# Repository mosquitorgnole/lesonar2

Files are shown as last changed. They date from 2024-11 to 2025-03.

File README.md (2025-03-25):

LeSonar 2
=========

We're directly selling our ultrasonic sonar development kit, and releasing it under an AGPL license so you can build projects on top of our sensor.

Links
-----
- [Main project link](https://tornyol.com/sonar)

Photos
------

 

Specifications
--------------

*   380x TDK Invensense T3902 PDM microphones.
*   Artix-7 A100T FPGA.
*   FT601Q parralel-to-usb bridge tested at up to 200MB/s.
*   32x 40khz Ultrasonic Piezoelectric emitters
*   2 free GPIOs

Capabilities
------------

### Active sonar

*   Optimized for 40KHz operation.
*   Up to 5°x5° beamwidth.
*   Range up to 8 meters depending on target sonar cross-section.

### Passive sonar

*   Can detect a bike air chamber leak at 3 meters.

Software
========

The sonar comes with two demoes
\- 2D Slicing camera, that shows the energyscape for a specific distance.
\- 3D Camera, that shows the reflected energy with a 3d point cloud.

Both examples are made with C99 C, using Raylib and Sokol for real-time 2D/3D visualization.

Attribution
======
The receiver hardware is based on the open-source [CP SoM One](https://github.com/controlpaths/cp_som_one)

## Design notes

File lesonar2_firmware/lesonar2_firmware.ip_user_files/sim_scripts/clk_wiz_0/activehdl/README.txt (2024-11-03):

################################################################################
# Vivado (TM) v2023.1 (64-bit)
#
# README.txt: Please read the sections below to understand the steps required to
#             run the exported script and how to fetch design source file details
#             from the file_info.txt file.
#
# Generated by export_simulation on Thu Mar 14 17:59:51 +0100 2024
#
################################################################################

1. Steps to run the generated simulation script

From the shell prompt in the current directory, issue the following command:-

./clk_wiz_0.sh

This command will launch the 'compile', 'elaborate' and 'simulate' functions
implemented in the script file for the 3-step flow. These functions are called
from the main 'run' function in the script file.

The 'run' function first calls the 'check_args' function, the purpose of which
is to verify the generated script arguments and print error if incorrect switch
is specified. The 'run' function then calls the 'setup' function, the purpose of
which is to specify custom or initialization commands. The function also executes
following sub-functions:-
'reset_run' if -reset_run switch is specified.
'reset_log' if -reset_log switch is specified.

The purpose of 'reset_run' function' is to delete the simulator generated design
data from the previous run and the purpose of 'reset_log' function' is to delete
the simulator generated log files.

The 'run' function then calls the 'init_lib' function, the purpose of which is to
create design library mappings and directories. This function is called before the
'compile' step. By default, if '-step' switch is specified with the script then the
script will execute that specfic step, else it will execute all steps applicable
for the target simulator.

For more information on the script, please type './clk_wiz_0.sh -help'

2. Design source file information

export_simulation generates a 'file_info.txt' file that contains design file information
based on the compile order when export_simulation was executed from Vivado. The file
contains information about the file name, type, library it is compiled into, whether
it is part of the IP, associated library, file path information in a comma separated
format. This file can be parsed to extract the required information for generating a
custom script or can be read from verification test infra.

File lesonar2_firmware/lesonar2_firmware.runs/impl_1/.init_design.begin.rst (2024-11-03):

<?xml version="1.0"?>
<ProcessHandle Version="1" Minor="0">
    <Process Command=".planAhead." Owner="alex" Host="" Pid="918656">
    </Process>
</ProcessHandle>

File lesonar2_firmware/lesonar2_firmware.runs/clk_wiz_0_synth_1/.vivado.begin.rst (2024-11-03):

<?xml version="1.0"?>
<ProcessHandle Version="1" Minor="0">
    <Process Command="vivado.bat" Owner="toussaint" Host="DESKTOP-L8QVRO0" Pid="20144" HostCore="16" HostMemory="017126408192">
    </Process>
</ProcessHandle>

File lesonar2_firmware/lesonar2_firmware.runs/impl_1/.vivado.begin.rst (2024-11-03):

<?xml version="1.0"?>
<ProcessHandle Version="1" Minor="0">
    <Process Command="vivado" Owner="alex" Host="atlap" Pid="918612" HostCore="8" HostMemory="16124260">
    </Process>
</ProcessHandle>

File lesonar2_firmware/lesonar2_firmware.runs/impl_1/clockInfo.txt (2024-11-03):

-------------------------------------
| Tool Version : Vivado v.2023.2
| Date         : Mon Oct 28 13:15:07 2024
| Host         : atlap
| Design       : design_1
| Device       : xc7a100t-fgg484-2--
-------------------------------------

For more information on clockInfo.txt clock routing debug file see https://support.xilinx.com/s/article/000035660?language=en_US

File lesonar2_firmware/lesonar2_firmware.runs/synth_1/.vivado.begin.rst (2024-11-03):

<?xml version="1.0"?>
<ProcessHandle Version="1" Minor="0">
    <Process Command="vivado" Owner="alex" Host="atlap" Pid="915598" HostCore="8" HostMemory="16124260">
    </Process>
</ProcessHandle>

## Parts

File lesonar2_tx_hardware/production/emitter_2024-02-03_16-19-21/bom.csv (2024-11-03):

Designator | Footprint | Quantity | Value | LCSC Part #
C1, C2 | CP_Elec_6.3x5.4 | 2 | 33uF | C72508
D1 | D_SMA | 1 | SS34 | C8678
H2, H4, H5, H6 | MountingHole_2.2mm_M2_DIN965_Pad_TopBottom | 4 | MountingHole_Pad | DNP
J1 | PinHeader_1x05_P2.54mm_Vertical | 1 | Conn_01x05_Pin
L1 | L_Sunlord_MWSA0503S | 1 | 22uH | C718383
LS1, LS10, LS11, LS12, LS13, LS14, LS15, LS16, LS17, LS18, LS19, LS2, LS20, LS21, LS22, LS23, LS24, LS25, LS26, LS27, LS28, LS29, LS3, LS30, LS31, LS32, LS4, LS5, LS6, LS7, LS73, LS74, LS75_2, LS75, LS76_2, LS76, LS77, LS78, LS79_2, LS79, LS8, LS80_2, LS80, LS81, LS82, LS83_2, LS83, LS84_2, LS84, LS85, LS86, LS87_2, LS87, LS88_2, LS88, LS9 | XDCR_MA40S4S | 56 | MA40S4S
R1 | 0603 | 1 | 82k
R2 | 0603 | 1 | 2k2
R3 | 0603 | 1 | 0.2
U1 | SOT-23-6 | 1 | MT3608 | C84817
U2 | Texas_HTSOP-8-1EP_3.9x4.9mm_P1.27mm_EP2.95x4.9mm_Mask2.4x3.1mm_ThermalVias | 1 | DRV8870DDA

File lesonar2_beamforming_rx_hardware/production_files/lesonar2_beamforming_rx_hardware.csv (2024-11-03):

# | Reference | Qty | Value | Footprint | DNP | JLCPCB
1 | C1, C3, C5, C7, C8, C9, C10, C11, C12, C13, C25, C26, C27, C28, C35, C36, C37, C38, C39 | 19 | 4u7 | Capacitor_SMD:C_0805_2012Metric |  | C162420
2 | C2, C4, C6 | 3 | 10u | Capacitor_SMD:C_0805_2012Metric |  | C105505
3 | C14, C15, C16, C17, C18, C19, C20, C21, C22, C29, C30, C31, C32, C40, C41, C42, C43, C44, C45, C46 | 20 | 0.47u | Capacitor_SMD:C_0402_1005Metric |  | C106255
4 | C23, C24 | 2 | 47u | Capacitor_SMD:C_1206_3216Metric |  | C385907
5 | C33, C34 | 2 | 100u | Capacitor_SMD:C_1206_3216Metric |  | C268006
6 | D1 | 1 | DONE | LED_SMD:LED_0603_1608Metric |  | C89814
7 | D2 | 1 | VCC | LED_SMD:LED_0603_1608Metric |  | C601673
8 | D3, D4, D5 | 3 | USER_LED | LED_SMD:LED_0603_1608Metric |  | C40378
9 | L1, L2, L3 | 3 | 2u2 | inductors:IND_LQH3NPN2R2MJRL |  | C341775
10 | R1 | 1 | 100k | Resistor_SMD:R_0402_1005Metric |  | C131362
11 | R2, R5 | 2 | 22k | Resistor_SMD:R_0402_1005Metric |  | C409681
12 | R3 | 1 | 120k | Resistor_SMD:R_0402_1005Metric |  | C323683
13 | R4 | 1 | 240k | Resistor_SMD:R_0402_1005Metric |  | C323663
14 | R6 | 1 | 33k | Resistor_SMD:R_0402_1005Metric |  | C416388
15 | R7, R8, R9, R10, R15, R16, R17 | 7 | 4k7 | Resistor_SMD:R_0402_1005Metric |  | C3017492
16 | R11 | 1 | 330 | Resistor_SMD:R_0402_1005Metric |  | C881192
17 | R12, R13, R14, R19 | 4 | 10k | Resistor_SMD:R_0402_1005Metric |  | C328298
18 | R18 | 1 | 100 | Resistor_SMD:R_0402_1005Metric |  | C471762
19 | U1 | 1 | XC7A75T-FGG484 | Package_BGA:FB-BGA-484_23.0x23.0mm_Layout22x22_P1.0mm |  | C396343
20 | U2 | 1 | TLV62565DBVR | Package_TO_SOT_SMD:SOT-23-5 |  | C87122
21 | U3, U4 | 2 | TLV62565DBVR | Package_TO_SOT_SMD:SOT-23-5 |  | C23902
22 | U5 | 1 | MX25L12833F | Package_SON:WSON-8-1EP_6x5mm_P1.27mm_EP3.4x4mm |  | C2802709
23 | X1 | 1 | SG-8018CE | Crystal:Crystal_SMD_3225-4Pin_3.2x2.5mm |  | C390488

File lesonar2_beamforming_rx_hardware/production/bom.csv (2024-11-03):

Designator | Footprint | Quantity | Value | LCSC Part #
C1, C10, C11, C12, C13, C25, C26, C27, C28, C3, C35, C36, C37, C38, C39, C44, C45, C468, C5, C51, C67, C68, C69, C7, C70, C71, C72, C73, C8, C9 | 0805 | 30 | 4u7 | C162420
C100, C101, C102, C103, C104, C105, C106, C107, C108, C109, C110, C111, C112, C113, C114, C115, C116, C117, C118, C119, C120, C121, C122, C123, C124, C125, C126, C127, C128, C129, C130, C131, C132, C133, C134, C135, C136, C137, C138, C139, C140, C141, C142, C143, C144, C145, C146, C147, C148, C149, C150, C151, C152, C153, C154, C155, C156, C157, C158, C159, C160, C161, C162, C163, C164, C165, C166, C167, C168, C169, C170, C171, C172, C173, C174, C175, C176, C177, C178, C179, C180, C181, C182, C183, C184, C185, C186, C187, C188, C189, C190, C191, C192, C193, C194, C195, C196, C197, C198, C199, C200, C201, C202, C203, C204, C205, C206, C207, C208, C209, C210, C211, C212, C213, C214, C215, C216, C217, C218, C219, C220, C221, C222, C223, C224, C225, C226, C227, C228, C229, C230, C231, C232, C233, C234, C235, C236, C237, C238, C239, C240, C241, C242, C243, C244, C245, C246, C247, C248, C249, C250, C251, C252, C253, C254, C255, C256, C257, C258, C259, C260, C261, C262, C263, C264, C265, C266, C267, C268, C269, C270, C271, C272, C273, C274, C275, C276, C277, C278, C279, C280, C281, C282, C283, C284, C285, C286, C287, C288, C289, C290, C291, C292, C293, C294, C295, C296, C297, C298, C299 | 0201 | 200 | 0.1u
C14, C15, C16, C17, C18, C19, C20, C21, C22, C29, C30, C31, C32, C40, C41, C42, C43, C466, C467, C55, C56, C57, C58, C59, C61, C62, C63, C64, C65 | 0402 | 29 | 0.47u | C106255
C2, C4, C6 | 0805 | 3 | 10u | C105505
C23, C24, C470, C60, C66 | 1206 | 5 | 47u | C385907
C300, C301, C302, C303, C304, C305, C306, C307, C308, C309, C310, C311, C312, C313, C314, C315, C316, C317, C318, C319, C320, C321, C322, C323, C324, C325, C326, C327, C328, C329, C330, C331, C332, C333, C334, C335, C336, C337, C338, C339, C340, C341, C342, C343, C344, C345, C346, C347, C348, C349, C350, C351, C352, C353, C354, C355, C356, C357, C358, C359, C360, C361, C362, C363, C364, C365, C366, C367, C368, C369, C370, C371, C372, C373, C374, C375, C376, C377, C378, C379, C380, C381, C382, C383, C384, C385, C386, C387, C388, C389, C390, C391, C392, C393, C394, C395, C396, C397, C398, C399, C400, C401, C402, C403, C404, C405, C406, C407, C408, C409, C410, C411, C412, C413, C414, C415, C416, C417, C418, C419, C420, C421, C422, C423, C424, C425, C426, C427, C428, C429, C430, C431, C432, C433, C434, C435, C436, C437, C438, C439, C440, C441, C442, C443, C444, C445, C446, C447, C448, C449, C450, C451, C452, C453, C454, C455, C456, C457, C458, C459, C460, C461, C462, C463, C464, C465, C47, C471, C48, C49, C50, C52, C75, C76, C77, C78, C79, C80, C81, C82, C83, C84, C85, C86, C87, C88, C89, C90, C91, C92, C93, C94, C95, C96, C97, C98, C99 | 0201 | 197 | 0.1u
C33, C34 | 1206 | 2 | 100u | C268006
C46 | 0603 | 1 | 2.2uF X7R | C23630
C469 | 0201 | 1 | 0.1u | C162420
C53, C54 | 0402 | 2 | 30pF | C107004
C74 | 01005 | 1 | 10nF | C15195
D1 | 0603 | 1 | DONE | C89814
D2 | 0603 | 1 | VCC | C2286
D3, D4 | 0603 | 2 | GREEN | C5123548
D5 | 0603 | 1 | GREEN | C5123548
FB1 | 1206 | 1 | Ferrite 3A | C515371
H1, H2, H3, H4, H5, H6 | MountingHole_2.2mm_M2_DIN965_Pad_TopBottom | 6 | MountingHole_Pad
IC1, IC10, IC100, IC101, IC102, IC103, IC104, IC105, IC106, IC107, IC108, IC109, IC11, IC110, IC111, IC112, IC113, IC114, IC115, IC116, IC117, IC118, IC119, IC12, IC120, IC121, IC122, IC123, IC124, IC125, IC126, IC127, IC128, IC129, IC13, IC130, IC131, IC132, IC133, IC134, IC135, IC136, IC137, IC138, IC139, IC14, IC140, IC141, IC142, IC143, IC144, IC145, IC146, IC147, IC148, IC149, IC15, IC150, IC151, IC152, IC153, IC154, IC155, IC156, IC157, IC158, IC159, IC16, IC160, IC161, IC162, IC163, IC164, IC165, IC166, IC167, IC168, IC169, IC17, IC170, IC171, IC172, IC173, IC174, IC175, IC176, IC177, IC178, IC179, IC18, IC180, IC181, IC182, IC183, IC184, IC185, IC186, IC187, IC188, IC189, IC19, IC190, IC191, IC192, IC193, IC194, IC195, IC196, IC197, IC198, IC199, IC2, IC20, IC200, IC201, IC202, IC203, IC204, IC205, IC206, IC207, IC208, IC209, IC21, IC210, IC211, IC212, IC213, IC214, IC215, IC216, IC217, IC218, IC219, IC22, IC220, IC221, IC222, IC223, IC224, IC225, IC226, IC227, IC228, IC229, IC23, IC230, IC231, IC232, IC233, IC234, IC235, IC236, IC237, IC238, IC239, IC24, IC240, IC241, IC242, IC243, IC244, IC245, IC246, IC247, IC248, IC249, IC25, IC250, IC251, IC252, IC253, IC254, IC255, IC256, IC257, IC258, IC259, IC26, IC260, IC261, IC262, IC263, IC264, IC265, IC266, IC267, IC268, IC269, IC27, IC270, IC271, IC272, IC273, IC274, IC275, IC276, IC277, IC278, IC279 | MMICT390200012 | 200 | MMICT3902-00-012 | C3032242
IC28, IC280, IC281, IC282, IC283, IC284, IC285, IC286, IC287, IC288, IC289, IC29, IC290, IC291, IC292, IC293, IC294, IC295, IC296, IC297, IC298, IC299, IC3, IC30, IC300, IC301, IC302, IC303, IC304, IC305, IC306, IC307, IC308, IC309, IC31, IC310, IC311, IC312, IC313, IC314, IC315, IC316, IC317, IC318, IC319, IC32, IC320, IC321, IC322, IC323, IC324, IC325, IC326, IC327, IC328, IC329, IC33, IC330, IC331, IC332, IC333, IC334, IC335, IC336, IC337, IC338, IC339, IC34, IC340, IC341, IC342, IC343, IC344, IC345, IC346, IC347, IC348, IC349, IC35, IC350, IC351, IC352, IC353, IC354, IC355, IC356, IC357, IC358, IC359, IC36, IC360, IC361, IC362, IC363, IC364, IC365, IC366, IC367, IC368, IC369, IC37, IC370, IC371, IC372, IC373, IC374, IC375, IC376, IC377, IC378, IC379, IC38, IC380, IC39, IC4, IC40, IC41, IC42, IC43, IC44, IC45, IC46, IC47, IC48, IC49, IC5, IC50, IC51, IC52, IC53, IC54, IC55, IC56, IC57, IC58, IC59, IC6, IC60, IC61, IC62, IC63, IC64, IC65, IC66, IC67, IC68, IC69, IC7, IC70, IC71, IC72, IC73, IC74, IC75, IC76, IC77, IC78, IC79, IC8, IC80, IC81, IC82, IC83, IC84, IC85, IC86, IC87, IC88, IC89, IC9, IC90, IC91, IC92, IC93, IC94, IC95, IC96, IC97, IC98, IC99 | MMICT390200012 | 180 | MMICT3902-00-012 | C3032242
J2, J3, J8 | PinHeader_1x05_P2.54mm_Vertical | 3 | Conn_01x05_Pin
J4 | BarrelJack_Horizontal | 1 | Barrel_Jack | C7428747
J5, J6, J7, J9 | PinHeader_1x02_P2.54mm_Vertical | 4 | Conn_01x02_Pin
L1, L2, L3 | L_Taiyo-Yuden_MD-3030 | 3 | 2u2 | C285840
PMUX2 | SOT-583-8 | 1 | TPS2117
R1 | 0402 | 1 | 100k | C25741
R10, R15, R16, R17, R19, R22, R23, R24, R25, R7, R8, R9 | 0402 | 12 | 4k7 | C25900
R11 | 0402 | 1 | 330 | C881192
R12, R13, R14, R21 | 0402 | 4 | 10k | C25744
R18 | 0402 | 1 | 100 | C25076
R2, R5 | 0402 | 2 | 22k | C25768
R20 | 0402 | 1 | 1k6 1% | C4908
R3 | 0402 | 1 | 120k | C323683
R4 | 0402 | 1 | 240k | C323663
R6 | 0402 | 1 | 33k | C25779
TP1, TP2 | TestPoint_Pad_1.0x1.0mm | 2 | TestPoint
U1 | Xilinx_FGG484 | 1 | XC7A100T-FGG484
U10, U11, U12, U13, U14, U15, U16, U17, U8, U9 | SC-70-6_L2.0-W1.3-P0.65-LS2.1-BL | 10 | SN74AUP2G34DCKR | C202161
U18 | Bosch_LGA-14_3x2.5mm_P0.5mm | 1 | IIM-42652
U2, U3, U4 | SOT-23-5 | 3 | TLV62565DBVR | C87122
U5 | WSON-8-1EP_6x5mm_P1.27mm_EP3.4x4mm | 1 | MX25L12833F | C2802709
U6 | USB-SMD_692622030100 | 1 | GSB343133HR | C464578
U7 | QFN-76-1EP_9x9mm_P0.4mm_EP5.81x6.31mm | 1 | FT601Q
X1 | Crystal_SMD_3225-4Pin_3.2x2.5mm | 1 | SG-8018CE | C390488
Y1 | Crystal_SMD_3225-4Pin_3.2x2.5mm | 1 | Crystal | C258956

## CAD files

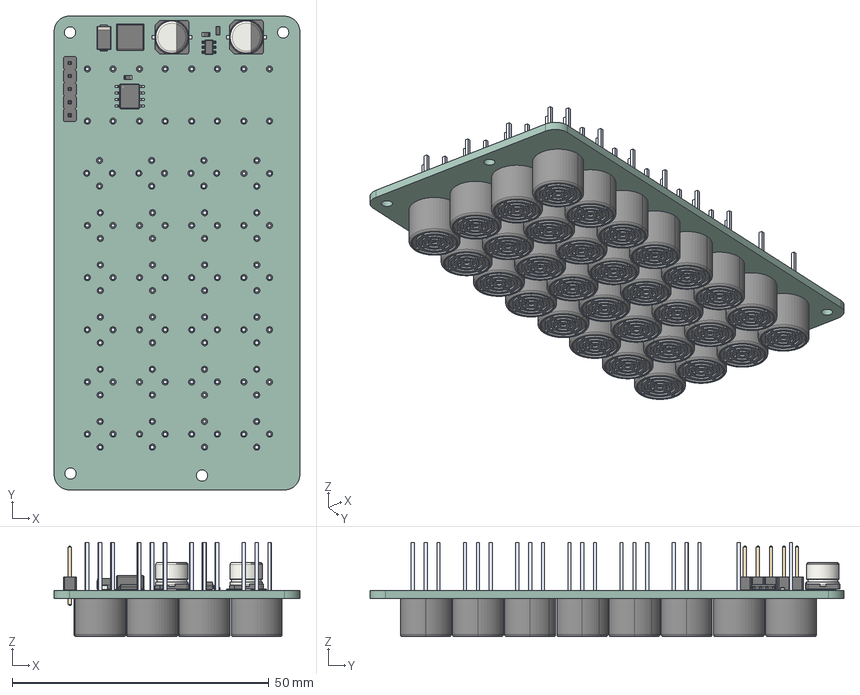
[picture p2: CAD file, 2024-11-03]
lesonar2_tx_hardware/lesonar2_tx_hardware.step
47.9 x 92.3 x 18.4 mm
R_0603_1608Metric x 3
PinHeader_1x05_P254mm_Vertical
D_SMA
Texas_HTSOP_8_1EP_39x49mm_P127mm_EP285x49mm_Mask24x31mm_ThermalVias
CQ assembly
SOT_23_6
CP_Elec_63x54 x 2
MA40S4R x 56
emitter_PCB

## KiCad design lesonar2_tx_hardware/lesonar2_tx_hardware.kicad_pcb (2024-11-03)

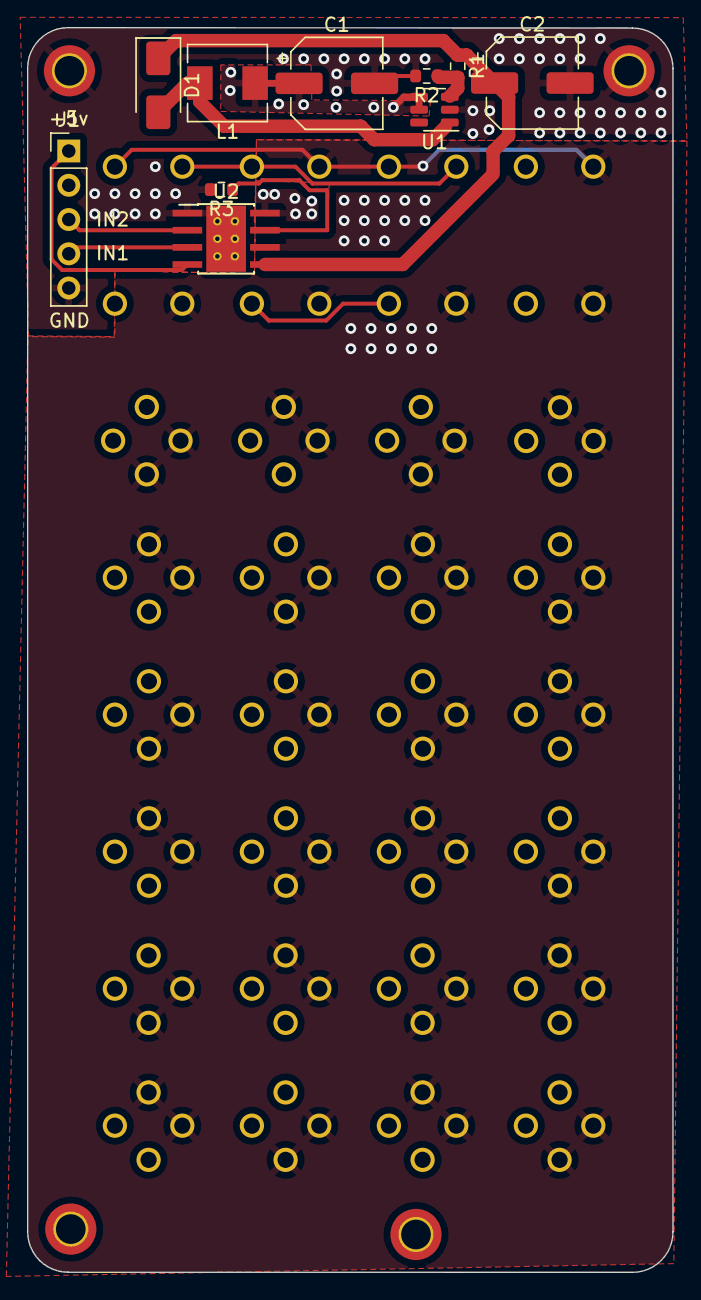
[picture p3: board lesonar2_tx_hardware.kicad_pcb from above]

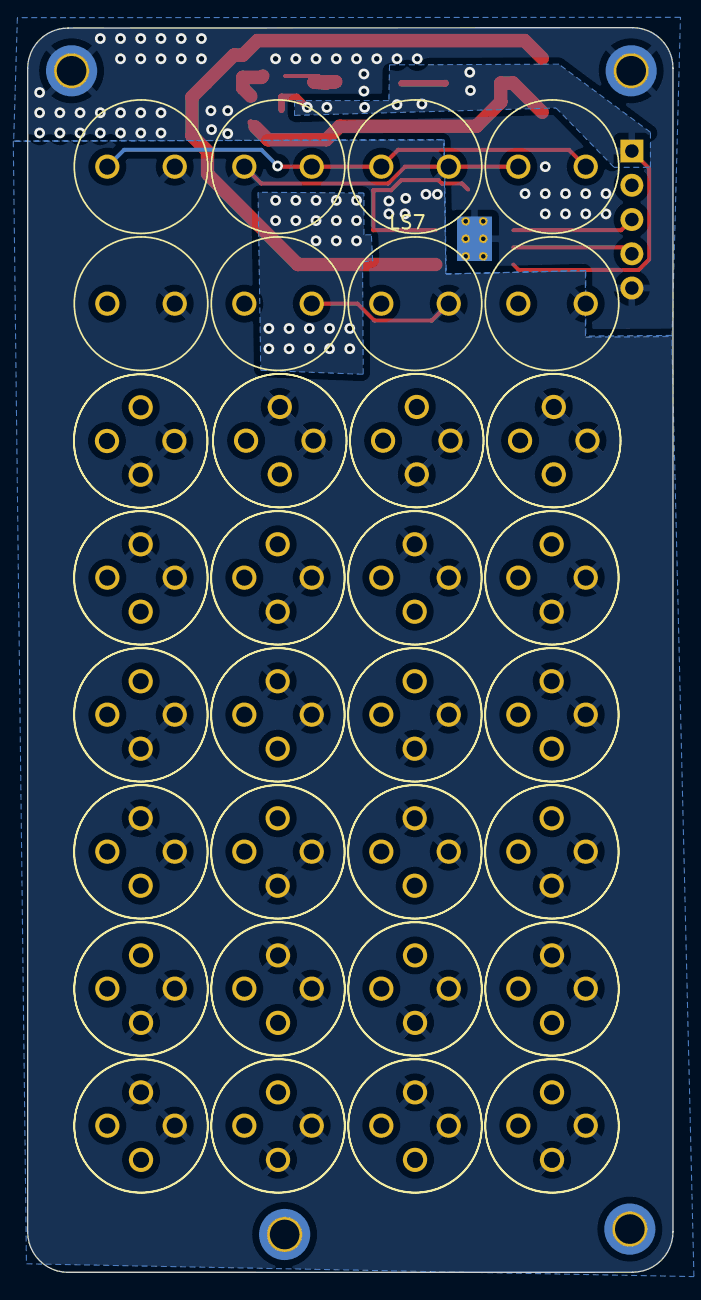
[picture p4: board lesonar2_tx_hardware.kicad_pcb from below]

Board: 2 copper layers, 47.9 x 92.3 mm, 70 parts (56 on the bottom side), 10 nets.

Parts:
C1, C2: 33uF; CP_Elec_6.3x5.4
D1: SS34; D_SMA
H2, H4, H5, H6: MountingHole_Pad; MountingHole_2.2mm_M2_DIN965_Pad_TopBottom
J1: Conn_01x05_Pin; PinHeader_1x05_P2.54mm_Vertical
L1: 22uH; L_Sunlord_MWSA0503S
LS1, LS2, LS3, LS4, LS5, LS6, LS7, LS8, LS9, LS10, LS11, LS12, LS13, LS14, LS15, LS16, LS17, LS18, LS19, LS20, LS21, LS22, LS23, LS24, LS25, LS26, LS27, LS28, LS29, LS30, LS31, LS32, LS73, LS74, LS75, LS75#2, LS76, LS76#2, LS77, LS78, LS79, LS79#2, LS80, LS80#2, LS81, LS82, LS83, LS83#2, LS84, LS84#2, LS85, LS86, LS87, LS87#2, LS88, LS88#2: MA40S4S; XDCR_MA40S4S
R1: 82k; R_0603_1608Metric
R2: 2k2; R_0603_1608Metric
R3: 0.2; R_0603_1608Metric
U1: MT3608; SOT-23-6
U2: DRV8870DDA; Texas_HTSOP-8-1EP_3.9x4.9mm_P1.27mm_EP2.95x4.9mm_Mask2.4x3.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

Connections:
+5V: C1.1, J1.1, L1.1, U1.4 (EN), U1.5 (IN), U2.4 (VREF)
+24V: C2.1, D1.1 (K), R1.1, U2.5 (VM)
GND: C1.2, C2.2, H2.1, H4.1, H5.1, H6.1, J1.5, R2.2, R3.2, U1.2 (GND), U2.1 (GND), U2.9 (GND)
unnamed: D1.2 (A), L1.2, U1.1 (SW)
unnamed: R1.2, R2.1, U1.3 (FB)
unnamed: R3.1, U2.7 (ISEN)
R6: J1.4, U2.3 (IN1)
TM: LS1.1, LS2.2, LS3.1, LS4.2, LS5.1, LS6.2, LS7.1, LS8.2, LS9.1, LS10.2, LS11.1, LS12.2, LS13.1, LS14.2, LS15.1, LS16.2, LS17.1, LS18.2, LS19.1, LS20.2, LS21.1, LS22.2, LS23.1, LS24.2, LS25.1, LS26.2, LS27.1, LS28.2, LS29.1, LS30.2, LS31.1, LS32.2, LS73.1, LS74.2, LS75.1, LS75#2.1, LS76.2, LS76#2.2, LS77.1, LS78.2, LS79.1, LS79#2.1, LS80.2, LS80#2.2, LS81.1, LS82.2, LS83.1, LS83#2.1, LS84.2, LS84#2.2, LS85.1, LS86.2, LS87.1, LS87#2.1, LS88.2, LS88#2.2, U2.6 (OUT1)
TP: LS1.2, LS2.1, LS3.2, LS4.1, LS5.2, LS6.1, LS7.2, LS8.1, LS9.2, LS10.1, LS11.2, LS12.1, LS13.2, LS14.1, LS15.2, LS16.1, LS17.2, LS18.1, LS19.2, LS20.1, LS21.2, LS22.1, LS23.2, LS24.1, LS25.2, LS26.1, LS27.2, LS28.1, LS29.2, LS30.1, LS31.2, LS32.1, LS73.2, LS74.1, LS75.2, LS75#2.2, LS76.1, LS76#2.1, LS77.2, LS78.1, LS79.2, LS79#2.2, LS80.1, LS80#2.1, LS81.2, LS82.1, LS83.2, LS83#2.2, LS84.1, LS84#2.1, LS85.2, LS86.1, LS87.2, LS87#2.2, LS88.1, LS88#2.1, U2.8 (OUT2)
U5: J1.3, U2.2 (IN2)

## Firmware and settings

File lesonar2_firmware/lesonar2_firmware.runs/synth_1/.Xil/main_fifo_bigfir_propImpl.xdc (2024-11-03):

set_property SRC_FILE_INFO {cfile:/home/alex/workspace/echoscanner-300/soft/hello_world_echoscanner_400/hello_world_echoscanner_400.srcs/constrs_1/new/main.xdc rfile:../../../hello_world_echoscanner_400.srcs/constrs_1/new/main.xdc id:1} [current_design]
set_property SRC_FILE_INFO {cfile:/home/alex/softwares/Xilinx/Vivado/2023.2/data/ip/xpm/xpm_cdc/tcl/xpm_cdc_gray.tcl rfile:../../../../../../../softwares/Xilinx/Vivado/2023.2/data/ip/xpm/xpm_cdc/tcl/xpm_cdc_gray.tcl id:2 order:LATE scoped_inst:write_fifo/gnuram_async_fifo.xpm_fifo_base_inst/gen_cdc_pntr.rd_pntr_cdc_inst unmanaged:yes} [current_design]
set_property SRC_FILE_INFO {cfile:/home/alex/softwares/Xilinx/Vivado/2023.2/data/ip/xpm/xpm_cdc/tcl/xpm_cdc_gray.tcl rfile:../../../../../../../softwares/Xilinx/Vivado/2023.2/data/ip/xpm/xpm_cdc/tcl/xpm_cdc_gray.tcl id:3 order:LATE scoped_inst:write_fifo/gnuram_async_fifo.xpm_fifo_base_inst/gen_cdc_pntr.wr_pntr_cdc_inst unmanaged:yes} [current_design]
set_property SRC_FILE_INFO {cfile:/home/alex/softwares/Xilinx/Vivado/2023.2/data/ip/xpm/xpm_cdc/tcl/xpm_cdc_gray.tcl rfile:../../../../../../../softwares/Xilinx/Vivado/2023.2/data/ip/xpm/xpm_cdc/tcl/xpm_cdc_gray.tcl id:4 order:LATE scoped_inst:write_fifo/gnuram_async_fifo.xpm_fifo_base_inst/gen_cdc_pntr.rd_pntr_cdc_dc_inst unmanaged:yes} [current_design]
set_property SRC_FILE_INFO {cfile:/home/alex/softwares/Xilinx/Vivado/2023.2/data/ip/xpm/xpm_cdc/tcl/xpm_cdc_gray.tcl rfile:../../../../../../../softwares/Xilinx/Vivado/2023.2/data/ip/xpm/xpm_cdc/tcl/xpm_cdc_gray.tcl id:5 order:LATE scoped_inst:write_fifo/gnuram_async_fifo.xpm_fifo_base_inst/gen_cdc_pntr.wr_pntr_cdc_dc_inst unmanaged:yes} [current_design]
set_property SRC_FILE_INFO {cfile:/home/alex/softwares/Xilinx/Vivado/2023.2/data/ip/xpm/xpm_memory/tcl/xpm_memory_xdc.tcl rfile:../../../../../../../softwares/Xilinx/Vivado/2023.2/data/ip/xpm/xpm_memory/tcl/xpm_memory_xdc.tcl id:6 order:LATE scoped_inst:accumulator/xpm_memory_sdpram_inst unmanaged:yes} [current_design]
set_property SRC_FILE_INFO {cfile:/home/alex/softwares/Xilinx/Vivado/2023.2/data/ip/xpm/xpm_memory/tcl/xpm_memory_xdc.tcl rfile:../../../../../../../softwares/Xilinx/Vivado/2023.2/data/ip/xpm/xpm_memory/tcl/xpm_memory_xdc.tcl id:7 order:LATE scoped_inst:{genblk2[0].accumulator/xpm_memory_sdpram_inst} unmanaged:yes} [current_design]
set_property SRC_FILE_INFO {cfile:/home/alex/softwares/Xilinx/Vivado/2023.2/data/ip/xpm/xpm_memory/tcl/xpm_memory_xdc.tcl rfile:../../../../../../../softwares/Xilinx/Vivado/2023.2/data/ip/xpm/xpm_memory/tcl/xpm_memory_xdc.tcl id:8 order:LATE scoped_inst:{genblk2[10].accumulator/xpm_memory_sdpram_inst} unmanaged:yes} [current_design]
set_property SRC_FILE_INFO {cfile:/home/alex/softwares/Xilinx/Vivado/2023.2/data/ip/xpm/xpm_memory/tcl/xpm_memory_xdc.tcl rfile:../../../../../../../softwares/Xilinx/Vivado/2023.2/data/ip/xpm/xpm_memory/tcl/xpm_memory_xdc.tcl id:9 order:LATE scoped_inst:{genblk2[11].accumulator/xpm_memory_sdpram_inst} unmanaged:yes} [current_design]
set_property SRC_FILE_INFO {cfile:/home/alex/softwares/Xilinx/Vivado/2023.2/data/ip/xpm/xpm_memory/tcl/xpm_memory_xdc.tcl rfile:../../../../../../../softwares/Xilinx/Vivado/2023.2/data/ip/xpm/xpm_memory/tcl/xpm_memory_xdc.tcl id:10 order:LATE scoped_inst:{genblk2[12].accumulator/xpm_memory_sdpram_inst} unmanaged:yes} [current_design]
set_property SRC_FILE_INFO {cfile:/home/alex/softwares/Xilinx/Vivado/2023.2/data/ip/xpm/xpm_memory/tcl/xpm_memory_xdc.tcl rfile:../../../../../../../softwares/Xilinx/Vivado/2023.2/data/ip/xpm/xpm_memory/tcl/xpm_memory_xdc.tcl id:11 order:LATE scoped_inst:{genblk2[13].accumulator/xpm_memory_sdpram_inst} unmanaged:yes} [current_design]
set_property SRC_FILE_INFO {cfile:/home/alex/softwares/Xilinx/Vivado/2023.2/data/ip/xpm/xpm_memory/tcl/xpm_memory_xdc.tcl rfile:../../../../../../../softwares/Xilinx/Vivado/2023.2/data/ip/xpm/xpm_memory/tcl/xpm_memory_xdc.tcl id:12 order:LATE scoped_inst:{genblk2[14].accumulator/xpm_memory_sdpram_inst} unmanaged:yes} [current_design]
set_property SRC_FILE_INFO {cfile:/home/alex/softwares/Xilinx/Vivado/2023.2/data/ip/xpm/xpm_memory/tcl/xpm_memory_xdc.tcl rfile:../../../../../../../softwares/Xilinx/Vivado/2023.2/data/ip/xpm/xpm_memory/tcl/xpm_memory_xdc.tcl id:13 order:LATE scoped_inst:{genblk2[15].accumulator/xpm_memory_sdpram_inst} unmanaged:yes} [current_design]
set_property SRC_FILE_INFO {cfile:/home/alex/softwares/Xilinx/Vivado/2023.2/data/ip/xpm/xpm_memory/tcl/xpm_memory_xdc.tcl rfile:../../../../../../../softwares/Xilinx/Vivado/2023.2/data/ip/xpm/xpm_memory/tcl/xpm_memory_xdc.tcl id:14 order:LATE scoped_inst:{genblk2[16].accumulator/xpm_memory_sdpram_inst} unmanaged:yes} [current_design]
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

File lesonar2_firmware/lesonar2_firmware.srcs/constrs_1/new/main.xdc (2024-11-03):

## FPGA Configuration I/O Options
set_property BITSTREAM.GENERAL.COMPRESS TRUE [current_design]
set_property CONFIG_VOLTAGE 3.3 [current_design]
set_property CFGBVS VCCO [current_design]

# I/O Pins
set_property -dict {PACKAGE_PIN T14  IOSTANDARD LVCMOS33} [get_ports {mic_clk}];

set_property -dict {PACKAGE_PIN M3 IOSTANDARD LVCMOS33} [get_ports {ft_rxf_n}];
set_property -dict {PACKAGE_PIN M2 IOSTANDARD LVCMOS33} [get_ports {ft_txe_n}];
set_property -dict {PACKAGE_PIN M1 IOSTANDARD LVCMOS33} [get_ports {ft_oe_n}];
set_property -dict {PACKAGE_PIN N4 IOSTANDARD LVCMOS33} [get_ports {ft_rd_n}];
set_property -dict {SLEW FAST DRIVE 4 PACKAGE_PIN L1 IOSTANDARD LVCMOS33} [get_ports {ft_wr_n}];

set_property -dict {PACKAGE_PIN E3 IOSTANDARD LVCMOS33} [get_ports {ft_be[0]}];
set_property -dict {PACKAGE_PIN G3 IOSTANDARD LVCMOS33} [get_ports {ft_be[1]}];
set_property -dict {PACKAGE_PIN F3 IOSTANDARD LVCMOS33} [get_ports {ft_be[2]}];
set_property -dict {PACKAGE_PIN H3 IOSTANDARD LVCMOS33} [get_ports {ft_be[3]}];


set_property -dict {PACKAGE_PIN U5 IOSTANDARD LVCMOS33} [get_ports {emitter_p}];
set_property -dict {PACKAGE_PIN R6 IOSTANDARD LVCMOS33} [get_ports {emitter_n}];

set_property -dict {SLEW FAST DRIVE 4 PACKAGE_PIN AB1  IOSTANDARD LVCMOS33} [get_ports {ft_data[0]}];
set_property -dict {SLEW FAST DRIVE 4 PACKAGE_PIN AB2  IOSTANDARD LVCMOS33} [get_ports {ft_data[1]}];
set_property -dict {SLEW FAST DRIVE 4 PACKAGE_PIN AA1  IOSTANDARD LVCMOS33} [get_ports {ft_data[2]}];
set_property -dict {SLEW FAST DRIVE 4 PACKAGE_PIN Y1  IOSTANDARD LVCMOS33} [get_ports {ft_data[3]}];
set_property -dict {SLEW FAST DRIVE 4 PACKAGE_PIN Y2  IOSTANDARD LVCMOS33} [get_ports {ft_data[4]}];
set_property -dict {SLEW FAST DRIVE 4 PACKAGE_PIN W1  IOSTANDARD LVCMOS33} [get_ports {ft_data[5]}];
set_property -dict {SLEW FAST DRIVE 4 PACKAGE_PIN W2  IOSTANDARD LVCMOS33} [get_ports {ft_data[6]}];
set_property -dict {SLEW FAST DRIVE 4 PACKAGE_PIN V2  IOSTANDARD LVCMOS33} [get_ports {ft_data[7]}];
set_property -dict {SLEW FAST DRIVE 4 PACKAGE_PIN U1  IOSTANDARD LVCMOS33} [get_ports {ft_data[8]}];
set_property -dict {SLEW FAST DRIVE 4 PACKAGE_PIN U2  IOSTANDARD LVCMOS33} [get_ports {ft_data[9]}];
set_property -dict {SLEW FAST DRIVE 4 PACKAGE_PIN T1  IOSTANDARD LVCMOS33} [get_ports {ft_data[10]}];
set_property -dict {SLEW FAST DRIVE 4 PACKAGE_PIN R1  IOSTANDARD LVCMOS33} [get_ports {ft_data[11]}];
set_property -dict {SLEW FAST DRIVE 4 PACKAGE_PIN R2  IOSTANDARD LVCMOS33} [get_ports {ft_data[12]}];
set_property -dict {SLEW FAST DRIVE 4 PACKAGE_PIN P1  IOSTANDARD LVCMOS33} [get_ports {ft_data[13]}];
set_property -dict {SLEW FAST DRIVE 4 PACKAGE_PIN P2  IOSTANDARD LVCMOS33} [get_ports {ft_data[14]}];
set_property -dict {SLEW FAST DRIVE 4 PACKAGE_PIN N2  IOSTANDARD LVCMOS33} [get_ports {ft_data[15]}];
set_property -dict {SLEW FAST DRIVE 4 PACKAGE_PIN K1  IOSTANDARD LVCMOS33} [get_ports {ft_data[16]}];
set_property -dict {SLEW FAST DRIVE 4 PACKAGE_PIN K2  IOSTANDARD LVCMOS33} [get_ports {ft_data[17]}];
set_property -dict {SLEW FAST DRIVE 4 PACKAGE_PIN J1  IOSTANDARD LVCMOS33} [get_ports {ft_data[18]}];
set_property -dict {SLEW FAST DRIVE 4 PACKAGE_PIN J2  IOSTANDARD LVCMOS33} [get_ports {ft_data[19]}];
set_property -dict {SLEW FAST DRIVE 4 PACKAGE_PIN H2  IOSTANDARD LVCMOS33} [get_ports {ft_data[20]}];
set_property -dict {SLEW FAST DRIVE 4 PACKAGE_PIN G1  IOSTANDARD LVCMOS33} [get_ports {ft_data[21]}];
set_property -dict {SLEW FAST DRIVE 4 PACKAGE_PIN G2  IOSTANDARD LVCMOS33} [get_ports {ft_data[22]}];
set_property -dict {SLEW FAST DRIVE 4 PACKAGE_PIN F1  IOSTANDARD LVCMOS33} [get_ports {ft_data[23]}];
set_property -dict {SLEW FAST DRIVE 4 PACKAGE_PIN E1  IOSTANDARD LVCMOS33} [get_ports {ft_data[24]}];
set_property -dict {SLEW FAST DRIVE 4 PACKAGE_PIN E2  IOSTANDARD LVCMOS33} [get_ports {ft_data[25]}];
set_property -dict {SLEW FAST DRIVE 4 PACKAGE_PIN D1  IOSTANDARD LVCMOS33} [get_ports {ft_data[26]}];
set_property -dict {SLEW FAST DRIVE 4 PACKAGE_PIN D2  IOSTANDARD LVCMOS33} [get_ports {ft_data[27]}];
set_property -dict {SLEW FAST DRIVE 4 PACKAGE_PIN C2  IOSTANDARD LVCMOS33} [get_ports {ft_data[28]}];
set_property -dict {SLEW FAST DRIVE 4 PACKAGE_PIN B1  IOSTANDARD LVCMOS33} [get_ports {ft_data[29]}];
set_property -dict {SLEW FAST DRIVE 4 PACKAGE_PIN B2  IOSTANDARD LVCMOS33} [get_ports {ft_data[30]}];
set_property -dict {SLEW FAST DRIVE 4 PACKAGE_PIN A1  IOSTANDARD LVCMOS33} [get_ports {ft_data[31]}];
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
